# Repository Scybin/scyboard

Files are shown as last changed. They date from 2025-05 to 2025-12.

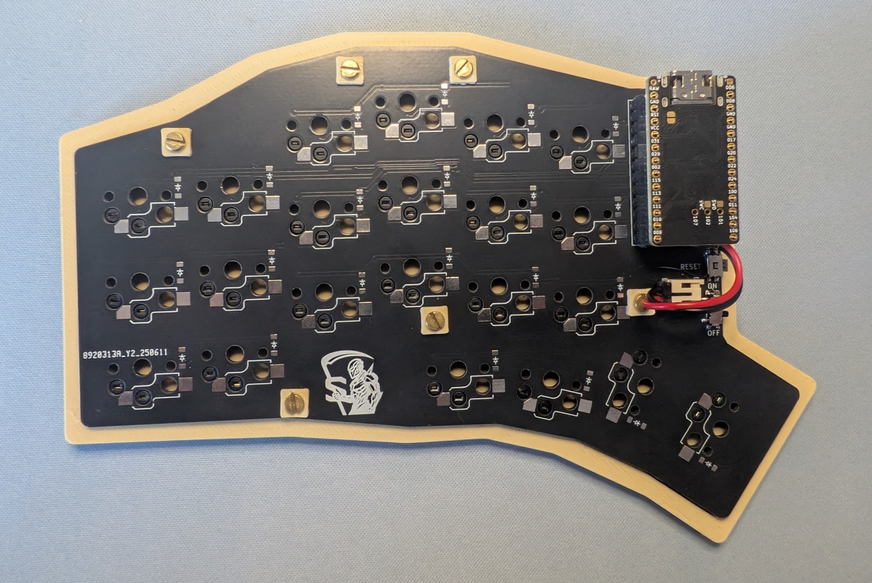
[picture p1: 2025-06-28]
images/assembled_case.png

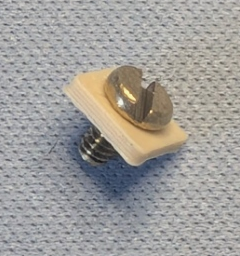
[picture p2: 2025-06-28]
images/screw_spacer.png

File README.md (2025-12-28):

# scyboard

scyboard
scyboard_plated

## 📚 Table of Contents

- [⚠️ Disclaimer](#disclaimer)
- [⌨️ Welcome](#welcome)
- [⚙️ Features](#features)
- [📊 Project Status](#project-status)
- [📦 Parts List](#parts-list)
- [🛠️ Build Guide](#build-guide)
- [💾 Firmware](#firmware)
- [🙏 Thanks](#thanks)
- [📄 License](#license)

## ⚠️ Disclaimer

This project has reached the fully working prototype stage. All core features have been tested and function as intended. However, as with any DIY hardware project, you should carefully review all files before manufacturing or assembly. The author(s) cannot guarantee flawless operation in every environment or configuration.

The author(s) take no responsibility for any damage, issues, or legal trouble that might result from using this project (see the license). Be sure to follow local laws regarding radio frequencies and DIY electronics.

## ⌨️ Welcome

Scyboard is a custom, open-source mechanical keyboard designed for ergonomic comfort and wireless functionality. Inspired by the Sweep and Corne keyboards, scyboard builds on these layouts and design principles. Every aspect was created using open-source tools, making it easy to modify, build, and share.

## ⚙️ Features

- Compact layout optimized for ergonomics
- ZMK firmware support
- USB-C connectivity & battery charging
- Bluetooth compatible
- Customizable keymaps, layers, and macros
- Layout is declared using Ergogen
- KiCad traces auto-routed using Freerouting
- Open source

## 📊 Project Status

The prototype has been built successfully. All aspects of the keyboard and firmware behave as expected.

## 📦 Parts List

*I am not sponsored or affiliated with the vendors linked below. This is where I prefer to purchase my products.*

| Part | Quantity | Description | Purchase Link | Datasheet |
|---|---|---|---|---|
| Microcontroller | 2 | nice!nano v2.0 | [Nice Keyboarrds nice!nano v2.0](https://typeractive.xyz/products/no-solder-spring-headers?variant=47196312502503) | [Nordic nRF52840](https://nicekeyboards.com/nice-nano) | 
| Pin Headers | 4 | Controller socketing system | [MAC8 spring-loaded pin headers](https://typeractive.xyz/products/no-solder-spring-headers?variant=47196312502503) | [MAC8 spring-loaded pin headers specifications](https://www.mac8sdk.co.jp/uploads/entry_meta/file_value/1117/mac8_2018a_jp-xb2.pdf) |
| Reset Button | 2 | Panasonic miniature momentary button | [Panasonic Reset Button](https://typeractive.xyz/products/reset-button) | [EVQPUC02K](https://cdn.shopify.com/s/files/1/0618/5674/3655/files/PANASONIC-EVQPUC02K.pdf) |
| Power Switch | 2 | Alps miniature SPDT switch | [ALPS Powr Switch](https://typeractive.xyz/products/power-switch) | [SSSS811101](https://cdn.shopify.com/s/files/1/0618/5674/3655/files/ALPS-SSSS811101.pdf) |
| Battery Jack | 2 | JST PH 2.0mm | [JST Battery Jack](https://typeractive.xyz/products/battery-jack) | [JST_PH_S2B-PH-K_1x02_P2.00mm_Horizontal](http://www.jst-mfg.com/product/pdf/eng/ePH.pdf) |
| Battery | 2 | 3.7V LiPo 110mAh (w/ JST adapter) | [Liter Bihuade Lithium Battery](https://typeractive.xyz/products/lithium-battery-110mah) | [301230](https://www.ufinebattery.com/images/upload/ufx0509-08-3-7v-75mah-lithium-ion-battery-product-datasheet.pdf) |
| Diode | 44 | SMD Diode | [Semtech SMD Diodes](https://typeractive.xyz/products/smd-diodes) | [SOD-123](https://www.onsemi.com/download/data-sheet/pdf/mmsd301t1-d.pdf) 									 |
| Hotswap Socket | 44 | Kailh Choc PCB Socket | [Kailh Hotswap Sockets](https://typeractive.xyz/products/hotswap-sockets) | [1350Connector](https://www.kailhswitch.com/Content/upload/pdf/202115927/CPG135001S30-data-sheet.pdf?rnd=943) |
| Choc V1/V2 Switch | 44 | Kailh Choc | [Lowprokb Ambients Silent Choc Switches](https://lowprokb.ca/products/ambients-silent-choc-switches) | |
| Choc Keycap | 44 | 40 x 1u, 4 x 1.5u | [FK MBK Choc Keycaps](https://typeractive.xyz/products/mbk-keycaps) | |
| Nut  (optional) | 12 | Inserts for bottom case | [uxcell Knurled Insert Nuts](https://www.amazon.com/dp/B07LBQFNQD?th=1) | |
| M2X3 Screw  (optional) | 24 | Screws for bottom case | [CO-RODE Screw Kit](https://www.amazon.com/gp/product/B01FTI8TM8/) | |
| M2X4 Screw  (optional) | 12 | Screws for bottom case | [CO-RODE Screw Kit](https://www.amazon.com/gp/product/B01FTI8TM8/) | |
| M2X6 Standoff (optional) | 10 | Standoffs for plate | [uxcell M2x6 Standoffs](https://a.co/d/fXHgMmH) | |
| Bottom Case (optional) | 2 | 3D printed bottom case | [Case STL Found Here](https://github.com/Scybin/scyboard/tree/master/3d) | |
| Plate (optional) | 2 | 3D printed plate | [Plate STL Found Here](https://github.com/Scybin/scyboard/tree/master/3d) | | 
| Screw Spacers (optional) | 12 | 3D printed spacers | [Screw Spacer STL Found Here](https://github.com/Scybin/scyboard/tree/master/3d) | |

## 🛠️ Build Guide

For assembling the keyboard hardware, I recommend following the guide for the Corne keyboard, as the assembly process is similar. You can find the guide here: [corne-cherry v2 buildguide](https://github.com/foostan/crkbd/blob/main/docs/corne-cherry/v2/buildguide_en.md)

In addition, here are some specific notes for the scyboard:
- There will be slight differences in the assembly process due to the different components used, but the overall steps will be similar.
- Place the nice!nano V2 microcontroller face down (flat side facing up).
- Solder the MCU jumper pads on the *same* (top) side of the PCB where the MCU wis mounted.
- Solder the JST battery connector jumpper pads on the *opposite* (back) side of the PCB where the MCU is mounted.

You can use the 3D printed bottom case without a plate. This requires M2x4 screws on the top, M2X3 screws on the bottom, knurled insert nuts, and 3D printed screw spacers. To mount the PCB directly to the case, use the 3D printed screw spacers between the screw and PCB. 

screw_spacer
assembled_case

If you want to add a plate to the build, you can replace the nuts and spacers by using M2x6 standoffs. I included files for a plate if you decide to go this route. You will need one insert nut and spacer for the hole next to the JST connector since the plate does not cover this area.

## 💾 Firmware

A ZMK module for this keyboard is available at:  
[zmk-keyboard-scyboard](https://github.com/Scybin/zmk-keyboard-scyboard)

To get started, add the module to your west.yaml file and follow the flashing instructions in the ZMK docs.

## 🙏 Thanks

- **[Ergogen](https://docs.ergogen.xyz/):** For keyboard PCB generation and configuration.
- **[Ceoloide](https://github.com/ceoloide/ergogen-footprints):** For providing footprints. An additional thanks for code inspiration.
- **[ZMK Firmware](https://zmk.dev/):** For providing the open-source keyboard architecture support.
- **[KiCad](https://www.kicad.org/):** For PCB viewing and editing.
- **[Freerouting](https://www.freerouting.app/):** For PCB auto-routing in KiCad.
- **[typeractive](https://typeractive.xyz/):** For design and parts inspiration.
- **[Sweep by David Philip Barr](https://github.com/davidphilipbarr/Sweep):** For key matrix and column stagger inspiration.
- **[Corne by foostan](https://github.com/foostan/crkbd):** For thumb cluster inspiration.
- **[FlatFootFox](https://flatfootfox.com/ergogen-introduction/):** For an Ergogen tutorial.
- **[nickcoutsos](https://nickcoutsos.github.io/keymap-editor/):** For the ZMK Keymap Editor browser app.
- **[joe-scotto](https://github.com/Scybin/scottokeebs/tree/dab518b84248842a73bc8f1feb84828ada38bbac/Extras/ScottoKicad):** For a 3d model library
- Open Source Community: For sharing knowledge, scripts, and inspiration.

## 📄 License

This project is licensed under the MIT License. See the [LICENSE](LICENSE) file for details.

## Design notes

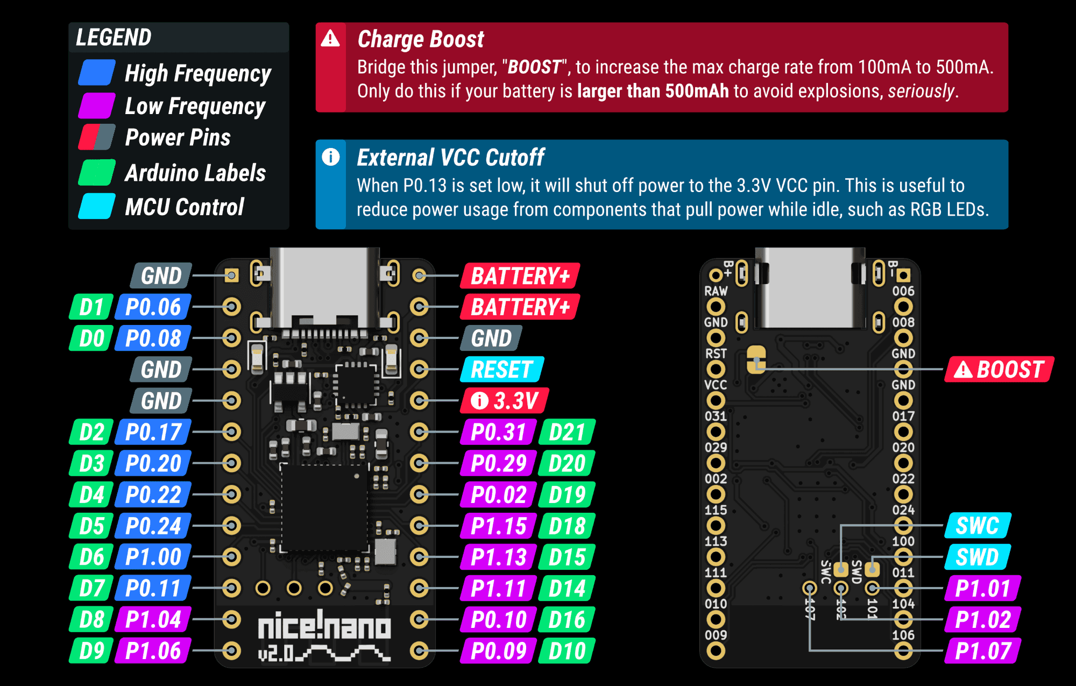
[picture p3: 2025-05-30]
images/nicenano_v2_pinout.png

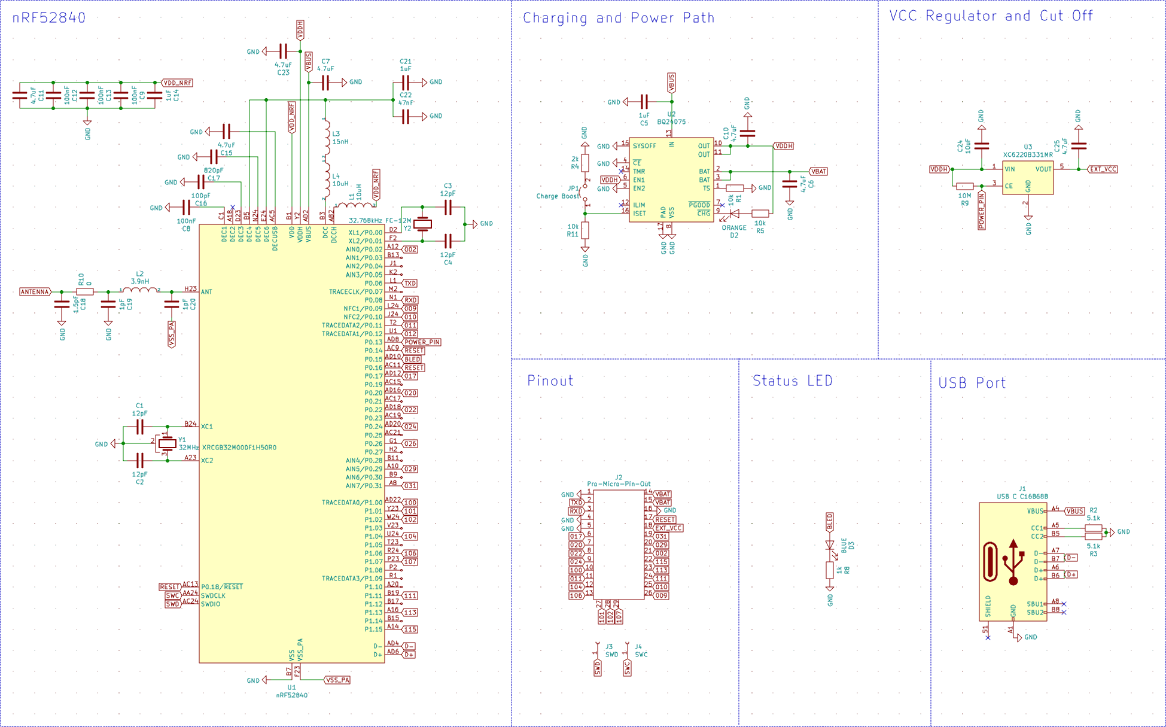
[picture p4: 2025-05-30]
images/nicenano_v2_schematic.png

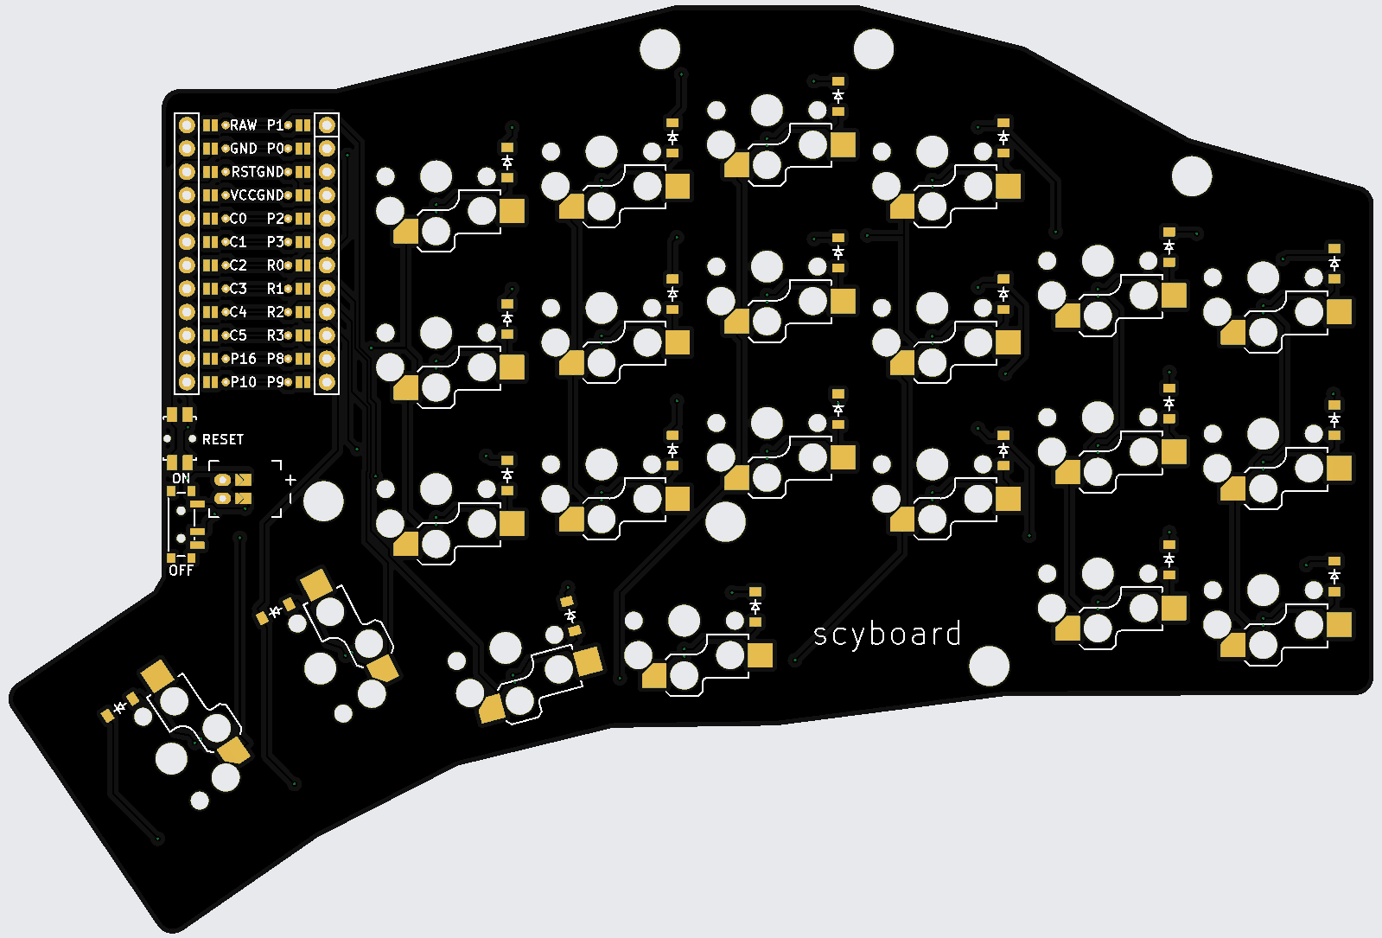
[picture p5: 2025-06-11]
images/pcb_bottom.png

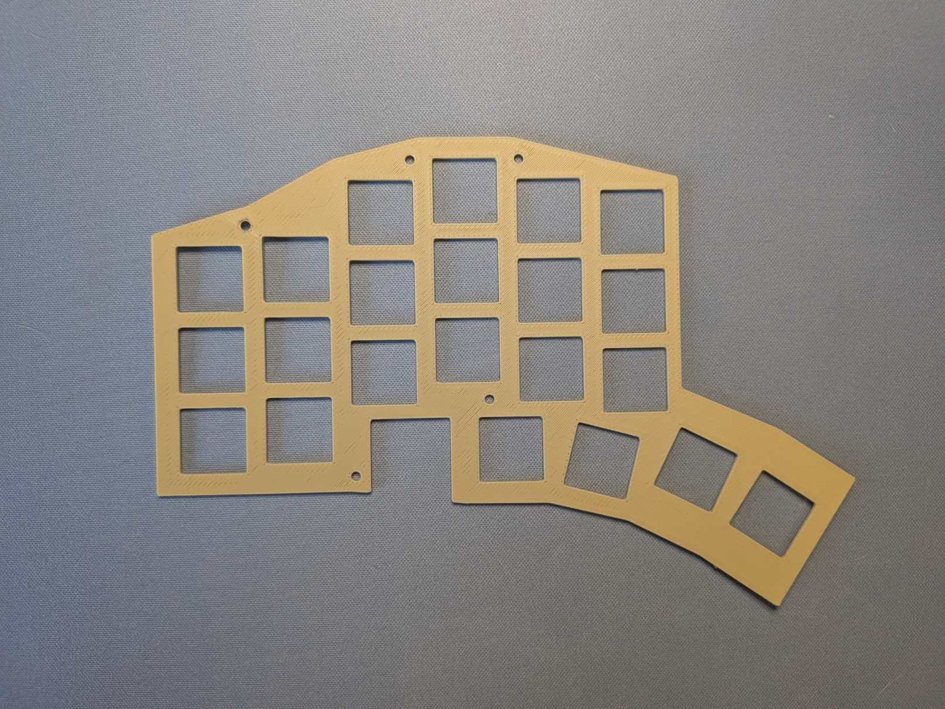
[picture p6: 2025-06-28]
images/plate.png

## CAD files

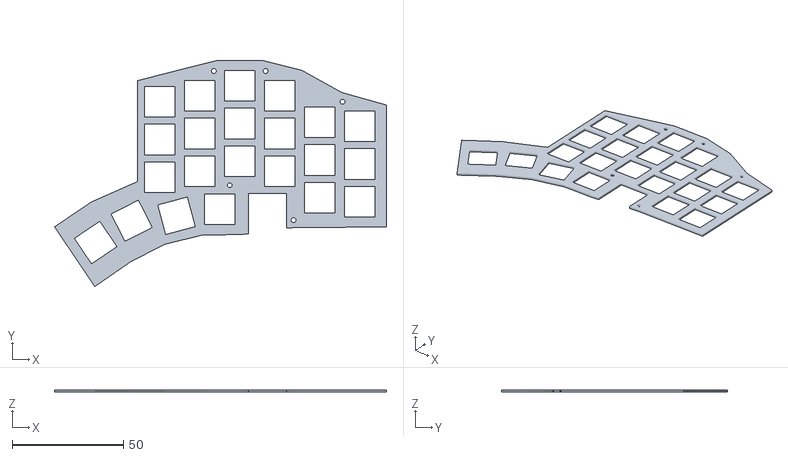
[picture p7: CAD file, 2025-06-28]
3d/scyboard_plate_r.stl
149.3 x 101.7 x 1.00

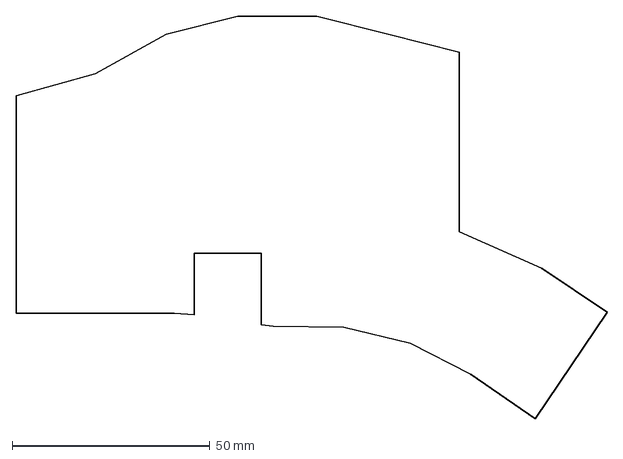
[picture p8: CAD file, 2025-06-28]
ergogen/output/outlines/switchplate.dxf
149.3 x 101.7 mm

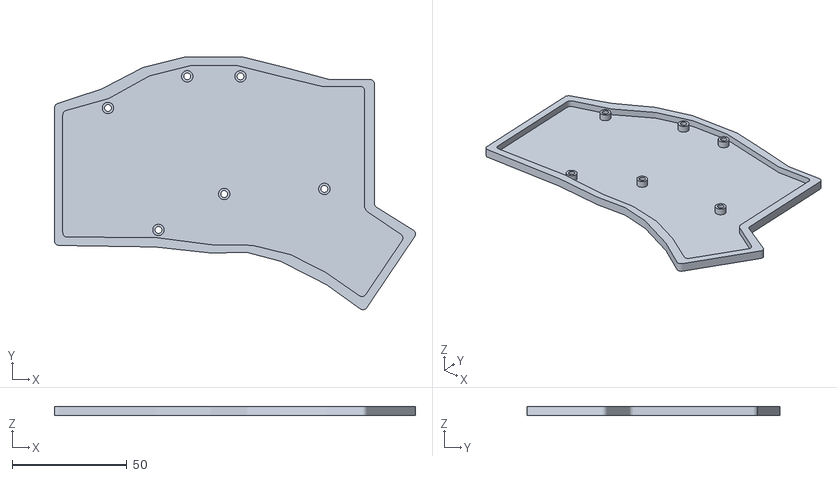
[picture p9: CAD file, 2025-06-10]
ergogen/output/cases/bottom_case.stl
157.6 x 110.3 x 4.00

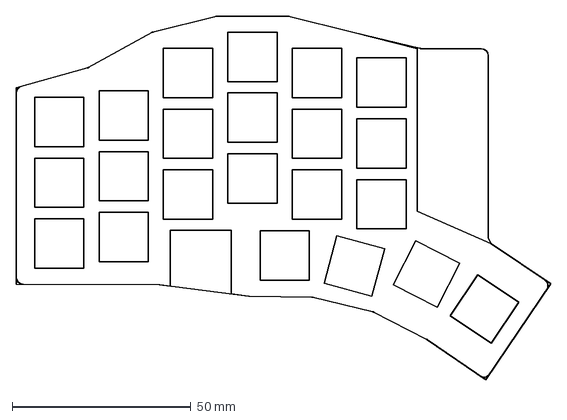
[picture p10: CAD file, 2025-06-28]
ergogen/output/outlines/combo.dxf
149.3 x 101.7 mm

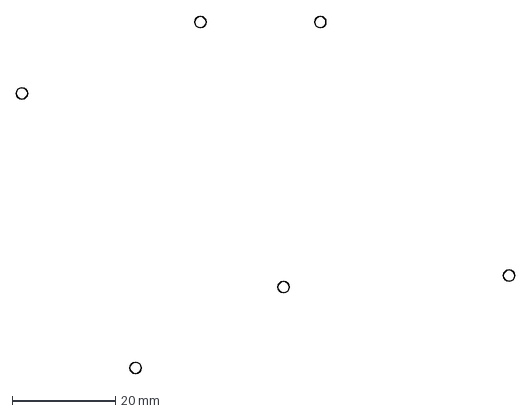
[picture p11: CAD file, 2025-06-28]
ergogen/output/outlines/plate_hole.dxf
96.7 x 69.3 mm

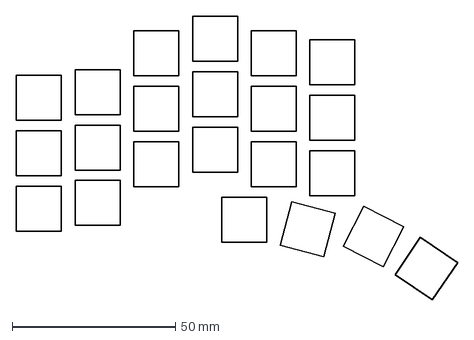
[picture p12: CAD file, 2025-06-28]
ergogen/output/outlines/switch_cutout.dxf
135.3 x 87.0 mm

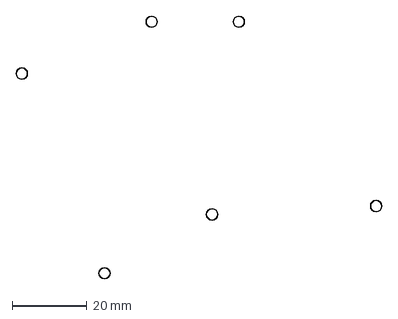
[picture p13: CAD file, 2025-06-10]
ergogen/output/outlines/mounting.dxf
97.5 x 70.1 mm

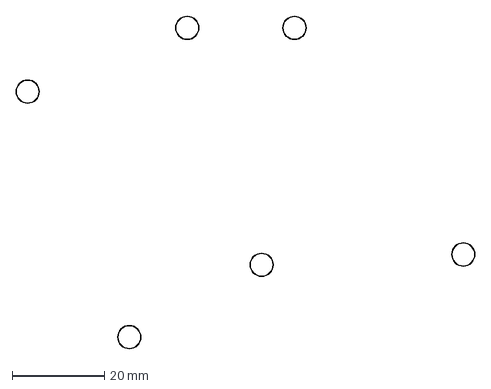
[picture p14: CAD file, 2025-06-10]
ergogen/output/outlines/standoff.dxf
99.5 x 72.1 mm

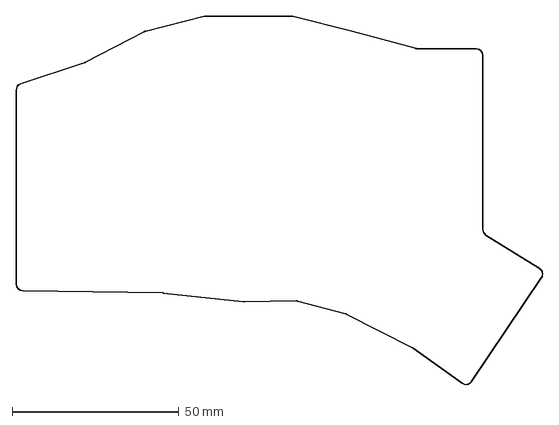
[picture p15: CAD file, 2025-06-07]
ergogen/output/outlines/xlBoard.dxf
157.7 x 110.4 mm

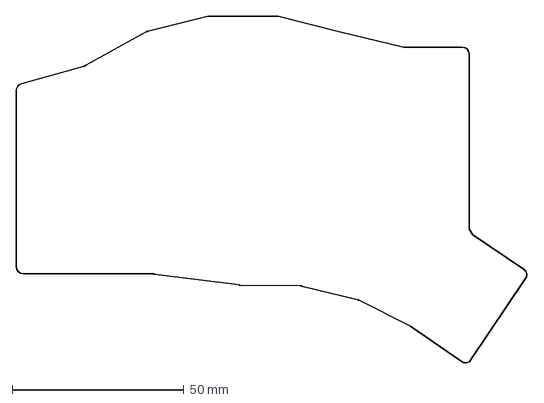
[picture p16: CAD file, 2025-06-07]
ergogen/output/outlines/pcb.dxf
148.8 x 101.0 mm

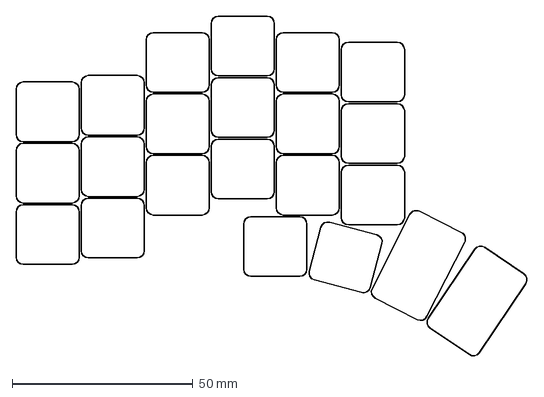
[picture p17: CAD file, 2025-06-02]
ergogen/output/outlines/keycap_outline.dxf
141.6 x 94.2 mm

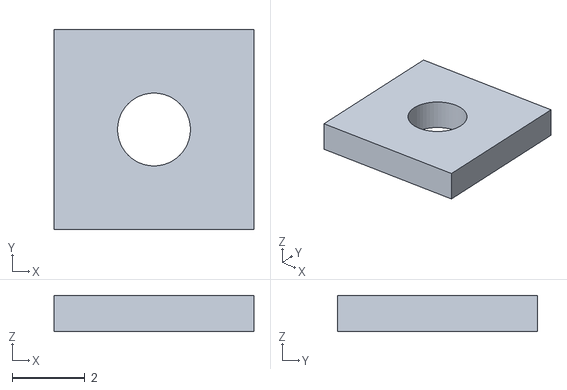
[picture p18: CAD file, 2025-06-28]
3d/screw_spacer.stl
5.50 x 5.50 x 1.00

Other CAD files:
ergogen/output/cases/switchplate_case.stl
3d/scyboard_plate_l.stl
3d/scyboard_bottom_case_l.stl
3d/scyboard_bottom_case_r.stl

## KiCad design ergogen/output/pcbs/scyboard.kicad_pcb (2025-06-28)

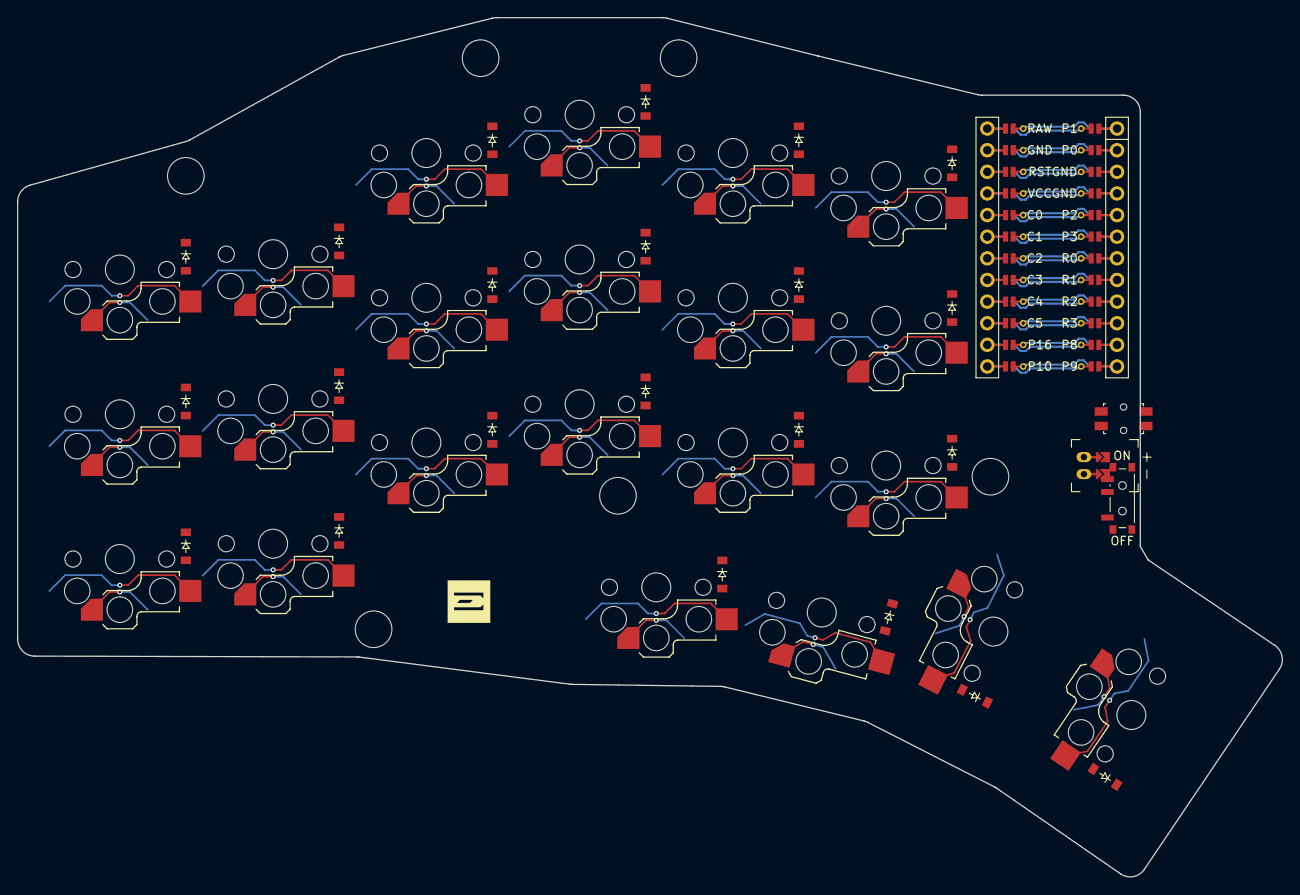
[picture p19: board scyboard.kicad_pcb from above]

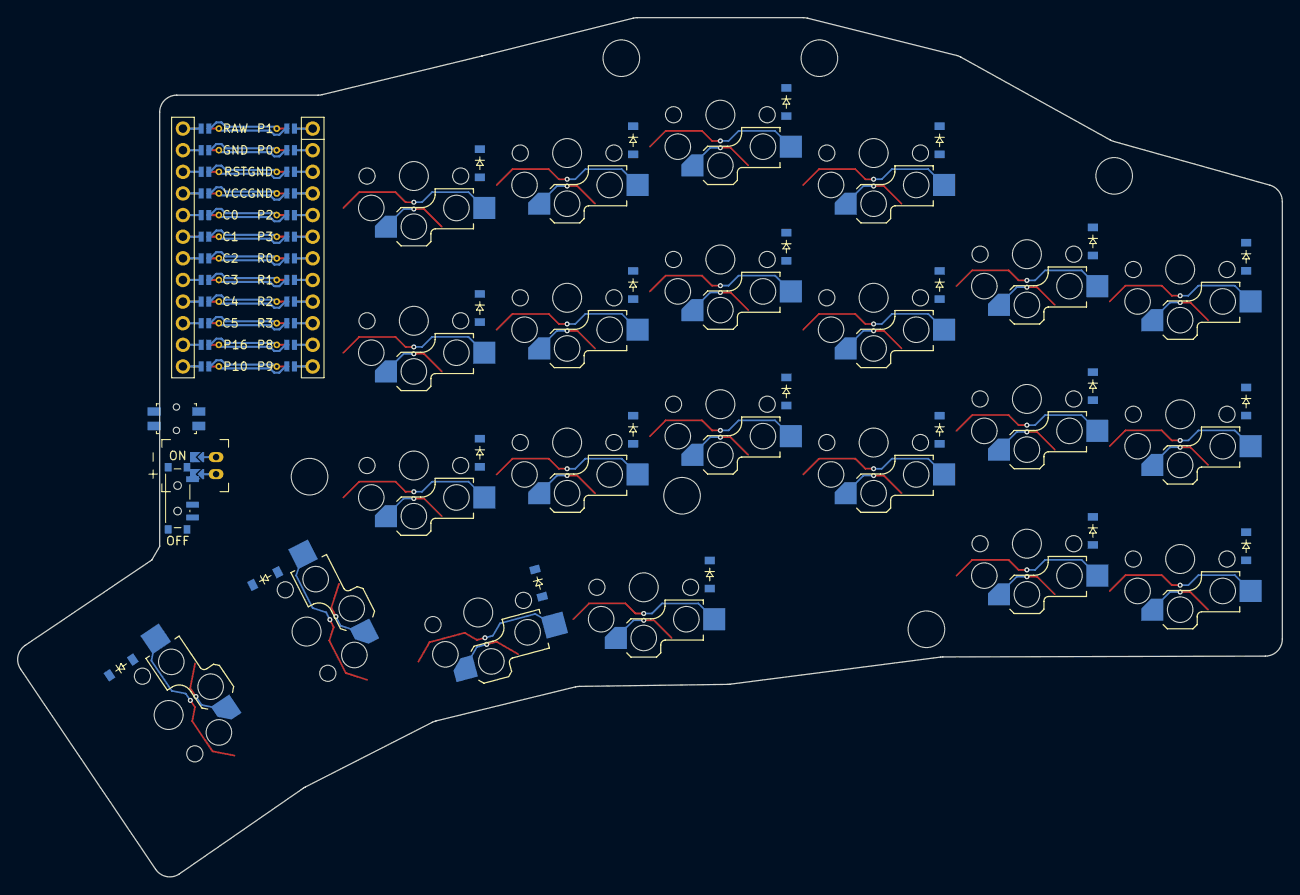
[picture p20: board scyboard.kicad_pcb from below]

Board: 2 copper layers, 148.5 x 100.9 mm, 77 parts (44 on the bottom side), 38 nets.

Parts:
D1, D2, D3, D4, D5, D6, D7, D8, D9, D10, D11, D12, D13, D14, D15, D16, D17, D18, D19, D20, D21, D22, D23, D24, D25, D26, D27, D28, D29, D30, D31, D32, D33, D34, D35, D36, D37, D38, D39, D40, D41, D42, D43, D44: diode_tht_sod123
JST1: battery_connector_jst_ph_2
LOGO1: utility_ergogen_logo
MCU1: mcu_nice_nano
MH1, MH2, MH3, MH4, MH5, MH6: mounting_hole_npth
PWR1: power_switch_smd_side
RST1: reset_switch_smd_side
S1, S2, S3, S4, S5, S6, S7, S8, S9, S10, S11, S12, S13, S14, S15, S16, S17, S18, S19, S20, S21, S22: switch_choc_v1_v2

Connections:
BAT_P: JST1.1, PWR1.1, PWR1.3
C0: MCU1.120, S1.1, S2.1, S3.1
C1: MCU1.119, S4.1, S5.1, S6.1
C2: MCU1.118, S7.1, S8.1, S9.1, S19.1
C3: MCU1.117, S10.1, S11.1, S12.1, S20.1
C4: MCU1.116, S13.1, S14.1, S15.1, S21.1
C5: MCU1.115, S16.1, S17.1, S18.1, S22.1
GND: JST1.2, MCU1.103, MCU1.104, MCU1.123, RST1.1, RST1.3
JST1_1: JST1.11, JST1.21, JST1.31
JST1_2: JST1.12, JST1.22, JST1.32
R0: D3.1, D6.1, D9.1, D12.1, D15.1, D18.1, D25.1, D28.1, D31.1, D34.1, D37.1, D40.1, MCU1.107
R1: D2.1, D5.1, D8.1, D11.1, D14.1, D17.1, D24.1, D27.1, D30.1, D33.1, D36.1, D39.1, MCU1.108
R2: D1.1, D4.1, D7.1, D10.1, D13.1, D16.1, D23.1, D26.1, D29.1, D32.1, D35.1, D38.1, MCU1.109
R3: D19.1, D20.1, D21.1, D22.1, D41.1, D42.1, D43.1, D44.1, MCU1.110
RAW: MCU1.124, PWR1.2
RST: MCU1.122, RST1.2, RST1.4
index_bottom_B: D13.2, D35.2, S13.2
index_home_B: D14.2, D36.2, S14.2
index_top_B: D15.2, D37.2, S15.2
inner_bottom_B: D16.2, D38.2, S16.2
inner_home_B: D17.2, D39.2, S17.2
inner_top_B: D18.2, D40.2, S18.2
layer_cluster_B: D20.2, D42.2, S20.2
middle_bottom_B: D10.2, D32.2, S10.2
middle_home_B: D11.2, D33.2, S11.2
middle_top_B: D12.2, D34.2, S12.2
outer_bottom_B: D1.2, D23.2, S1.2
outer_home_B: D2.2, D24.2, S2.2
outer_top_B: D3.2, D25.2, S3.2
pinky_bottom_B: D4.2, D26.2, S4.2
pinky_home_B: D5.2, D27.2, S5.2
pinky_top_B: D6.2, D28.2, S6.2
reach_cluster_B: D22.2, D44.2, S22.2
ring_bottom_B: D7.2, D29.2, S7.2
ring_home_B: D8.2, D30.2, S8.2
ring_top_B: D9.2, D31.2, S9.2
space_cluster_B: D21.2, D43.2, S21.2
tuck_cluster_B: D19.2, D41.2, S19.2

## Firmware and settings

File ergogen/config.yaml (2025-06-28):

meta:
  engine: 4.1.0
  name: scyboard
  version: 1.0
  author: Scybin
  url: https://github.com/Scybin/scyboard

units:

  # Key Variables
  kx: cx # 18 mm width
  ky: cy # 17 mm height
  px: kx + 2 # horizontal padding (20mm)
  py: ky + 2 # vertical padding (19mm)
  ks: 18.5 # horizontal space between columns (default: 19)
  kp: 17.5 # vertical padding between keys (deafult: 19)
  kcow: 13.8 # key cutout hole width
  kcoh: 13.8 # key cutout hole height
  keycw: 17.5 # keycap width (cherry: 18, choc: 17.5)
  keych: 16.5 # keycap height (cherry: 18, choc: 16.5)  
  switch_rotation: 180 # Hotswap south, led north

  # Diode Variables
  vertical_diode_shift: 1.5 # How much to shift to avoid overlap
  horizontal_diode_shift: -0.5 kcow - 0.85
  diode_rotation: -180 # Diode rotation

  # Controller Variables
  mcu_width: 18 # x-axis
  mcu_height: 33 # y-axis
  mcu_padding: 1.5

  # Reset Switch Variables
  rst_x: 27.884 # Reset switch position on x-axis
  rst_y: -28.5 # Reset switch position on y-axis

  # On Off Switch Variables
  pwr_x: 27.725 # On off switch position on x-axis
  pwr_y: rst_y-9.35 # On off switch position on y-axis

  # JST Variables
  jst_x: pwr_x-4.5 # JST connector position on x-axis
  jst_y: -34.01 # JST connector position on y-axis
  jst_shift: 3.5 # JST footprint center point shift

  # Screw variables
  screw_size: 1.5 # M2 flathead screw
  screw_x: (-kx/2) # Screw position on x-axis
  screw_y: (-ky/2) # Screw position on y-axis
  switchplate_screw_hole: 1.1 # Switchplate screw hole radius

  # Standoff variables
  standoff_size: 2.5 # Threaded screw inserts 3.2mm wide, and 3mm tall
  spacer_radius: 2.15 # M2 standoffs
  spacer_diameter: spacer_radius * 2

  # Case variables
  case_x: kx+8 # Case position on x-axis
  case_y: ky+8 # Case position on y-axis

points:
  zones:
    # Main key matrix
    matrix:
      key:
        padding: ky
        spread: kx
        tags:
          - key
          - matrix_key
      anchor.shift: [50,-100] # Fix KiCad placement
      columns:
        outer:
          key:
            column_net: C0
        pinky:
          key:
            column_net: C1
            stagger: 0.1cx
        ring:
          key:
            column_net: C2
            stagger: 0.66cx
        middle:
          key:
            column_net: C3
            stagger: 0.25cx
        index:
          key:
            column_net: C4
            stagger: -0.25cx
        inner:
          key:
            column_net: C5
            stagger: -0.15cx
      rows:
        bottom:
          row_net: R2
        home:
          row_net: R1
        top:
          row_net: R0

    # Thumb cluster
    thumb:
      key:
        padding: ky
        spread: kx
        stagger: 1
        tags:
          - key
          - thumb_key
      anchor:
        ref: matrix_index_bottom
      columns:
        tuck:
          key:
            column_net: C2
            name: thumb_tuck
            shift: [-0.5cx, -1cx]
        layer: 
          key:
            column_net: C3
            name: thumb_layer
            shift: [-0.42cx, -1.22cx]
            rotate: -15
        space:
          key:
            column_net: C4
            name: thumb_space
            width: 1.5kx
            shift: [-0.3cx, -1.4cx]
            rotate: -117
        reach:
          key:
           column_net: C5
           name: thumb_reach
           width: 1.5kx
           shift: [-0.4cx, -2cx]
           rotate: -124
      rows:
        cluster:
          row_net: R3
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

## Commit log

2025-05-30 Add nicenano pinout and schematics
2025-05-31 Update kicad
    [keyboard.kicad_pcb, scyboard.kicad_pcb, scyboard.kicad_sch]
2025-06-02 Add ceoloide footprints
2025-06-02 Add ceoloide footprint
2025-06-05 Reverse mount MCU
    [scyboard.kicad_pcb]
2025-06-05 Generate PCB
    [scyboard.kicad_pcb]
2025-06-08 Add KiCad pcb
    [combo.dxf, demo.dxf, master.dxf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]
2025-06-08 Add Gerbers
    [scyboard-B_Cu.gbr, scyboard-B_Mask.gbr, scyboard-B_Paste.gbr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]
2025-06-10 Update PCB
    [scyboard.kicad_pcb]
2025-06-10 Remove case and drill holes from config
2025-06-10 Update README.md
    Add bottom case, nuts, and screws to parts list.
2025-06-10 Update README.md
    Correct purchase link for m2 screws
2025-06-11 Generate gerbers
    [scyboard-B_Cu.gbr, scyboard-B_Mask.gbr, scyboard-B_Paste.gbr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]
2025-06-11 Add top and bottom JLCPCB Prototype photos
2025-06-22 Mill-Max General Technical Specifications datasheet
2025-06-22 Add Mill-Max General Technical Specifications datasheet
2025-06-27 Clarify jumper pad solder positions in Build Guide
    Update README.md
2025-06-28 Add plate files
    [combo.dxf, m2x3_spacer.stl, plate_hole.dxf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]
2025-06-28 Add case assembly to the build guide
2025-06-28 Add assembled case image
2025-06-28 Add case photos
2025-06-28 Update plate 3D files
    [scyboard_plate_l.stl, scyboard_plate_r.stl]
2025-06-28 Add scyboard plated photo
2025-06-28 Add screw spacer image
2025-06-28 Update parts list for case materials
2025-06-28 Update screw spacer 3D file
    [screw_spacer.stl]
2025-06-28 Add links to 3D print STL files
2025-12-28 Update quantity of Machine Sockets and Pins to 4
    Purchase 2x units, which = 4x parts
2025-12-28 Change 'Machine Sockets and Pins' to 'Pin Headers'
    Updated component names and links in the parts list.
